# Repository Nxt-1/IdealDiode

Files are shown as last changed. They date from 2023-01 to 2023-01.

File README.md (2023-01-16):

# IdealDiode

A small implementation around a TI LM74700 ideal diode controller.

Ideal diode controllers are an idealistic approximation of a diode one-way current blocking functionality. This is achieved by switching an N-channel MOSFET when conduction is desired and using the MOSFET's internal body diode to block current otherwise. The TI part monitors the input and output voltage and drives the transistor when current need to block (i.e. when V_IN > V_OUT).

By fully saturating the transitor's gate, the voltage drop source and drain is in the order of tens of milivolts instead of the typical 700mV for a silicon diode.

## Use Case

This project is designed to be used when charching multiple 36V nominal (42V max) lithium battery packs in parallel. Specifically batteries with separated charge port BMS, that are always energised. If no protection was implemented, connecting the batteries in parallel could cause the full battery current of a battery with a higher state of charge to flow through the other battery's chargeport. Using a regular diode would effectively lower the maximum charge voltage by the diode's voltage drop, thus decreasing the usable battery capacity. Hence the ideal diode circuit.

## Specifactions

The device is designed to withstand 42V nomimal and a charge current of 5A.

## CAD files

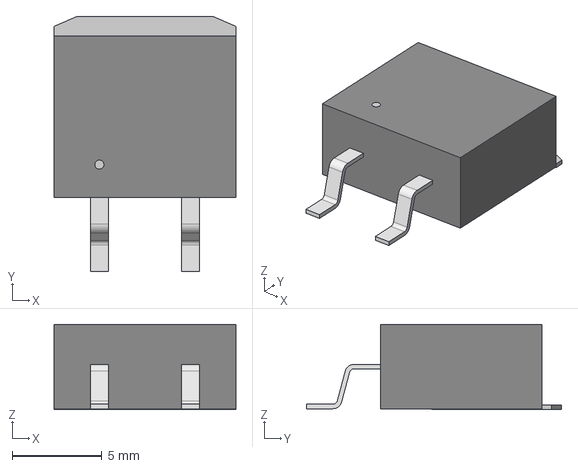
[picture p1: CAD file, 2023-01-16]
TRANS_R5009FNJ_ROM.step
10.1 x 14.2 x 4.75 mm

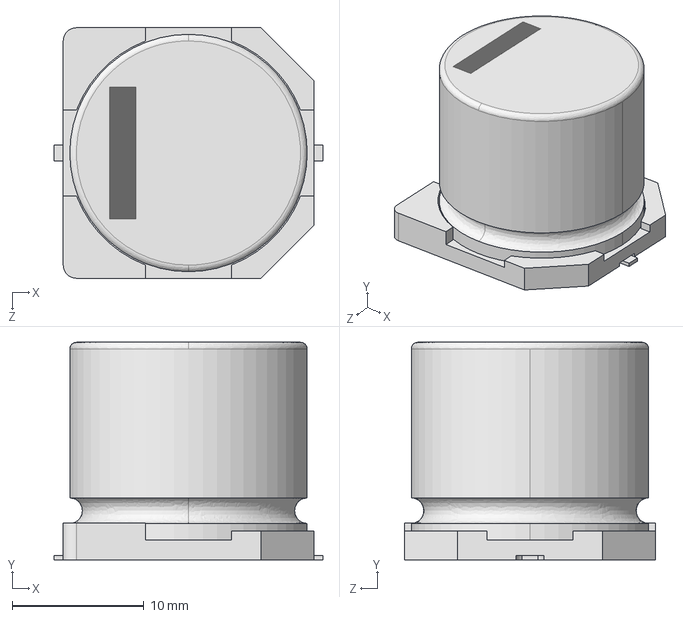
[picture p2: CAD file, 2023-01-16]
EEVFK2A221M.step
20.4 x 16.5 x 19.0 mm

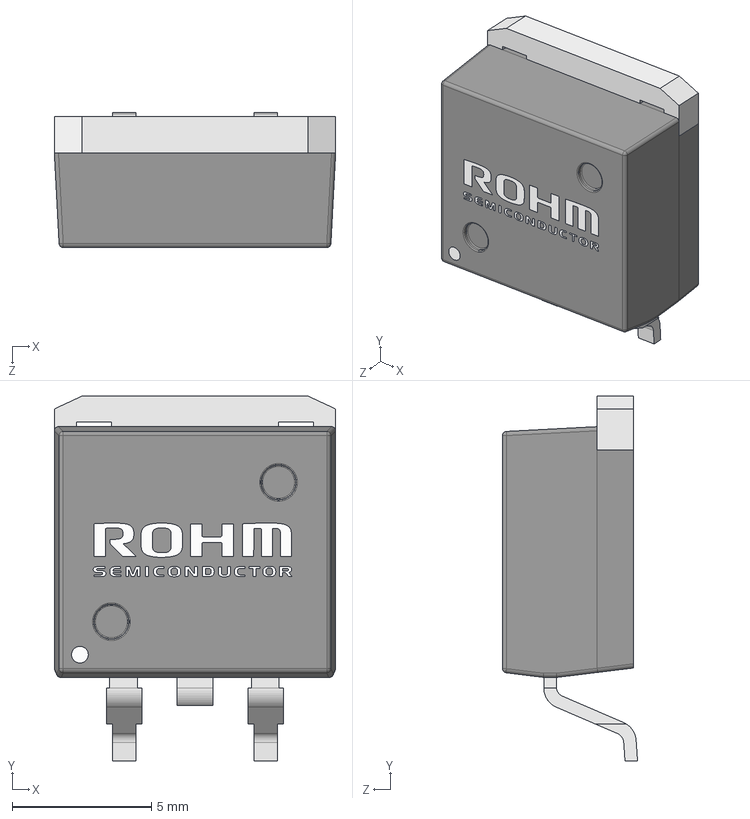
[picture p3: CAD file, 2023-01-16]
RSJ650N10TL.stp
10.1 x 13.1 x 4.85 mm
LPTS
Rohm Logo-LAPTOP-NQA1DCQ3

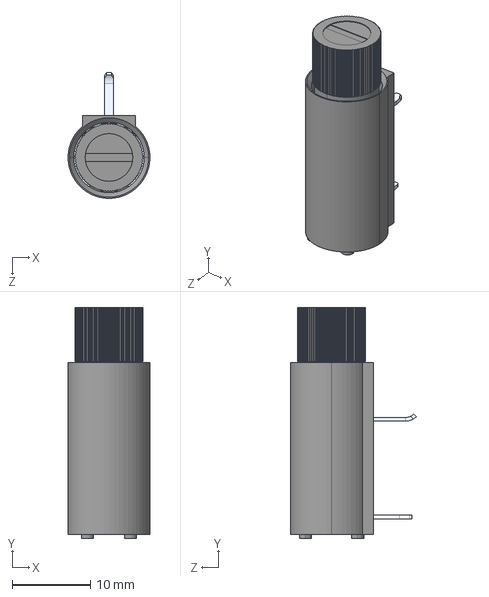
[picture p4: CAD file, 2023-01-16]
keystone-PN4525.STEP
10.5 x 29.6 x 16.1 mm

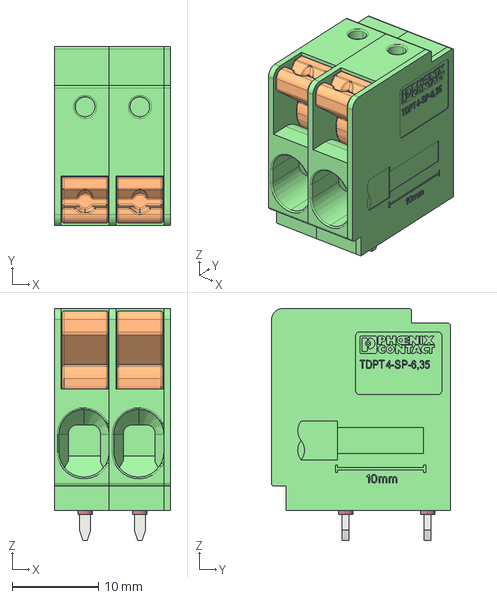
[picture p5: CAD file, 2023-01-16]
1017521.step
13.5 x 20.8 x 26.9 mm

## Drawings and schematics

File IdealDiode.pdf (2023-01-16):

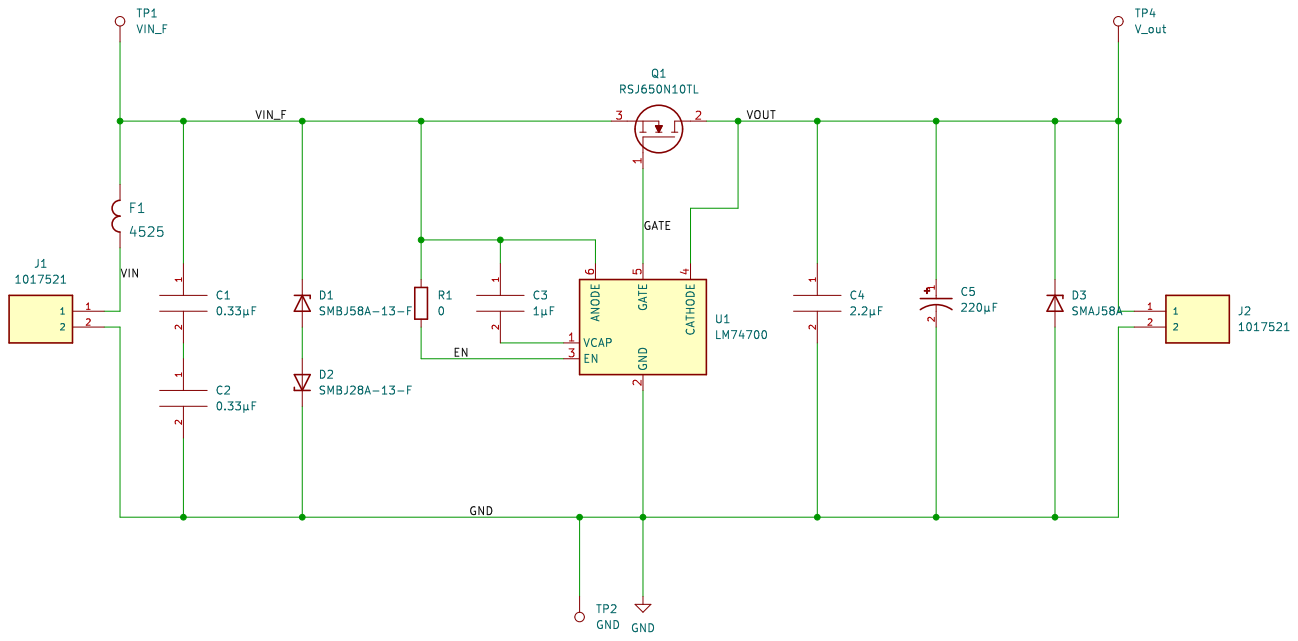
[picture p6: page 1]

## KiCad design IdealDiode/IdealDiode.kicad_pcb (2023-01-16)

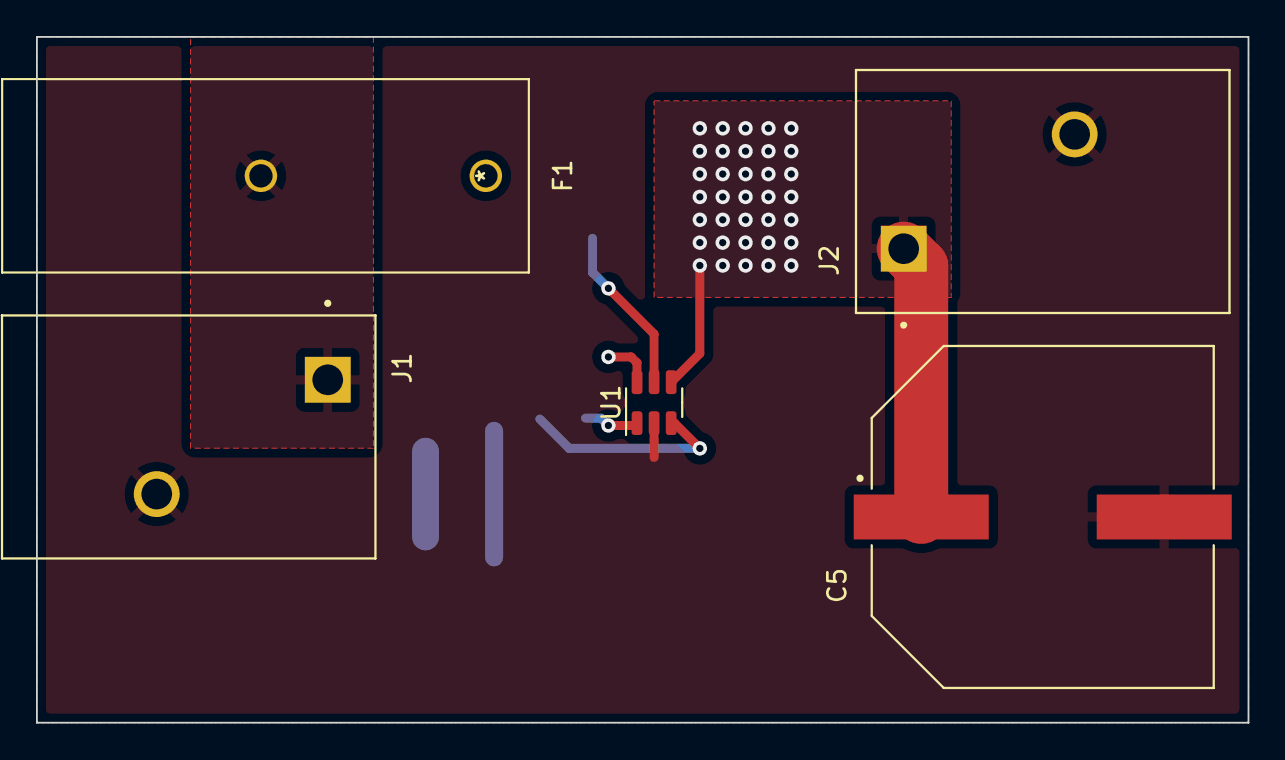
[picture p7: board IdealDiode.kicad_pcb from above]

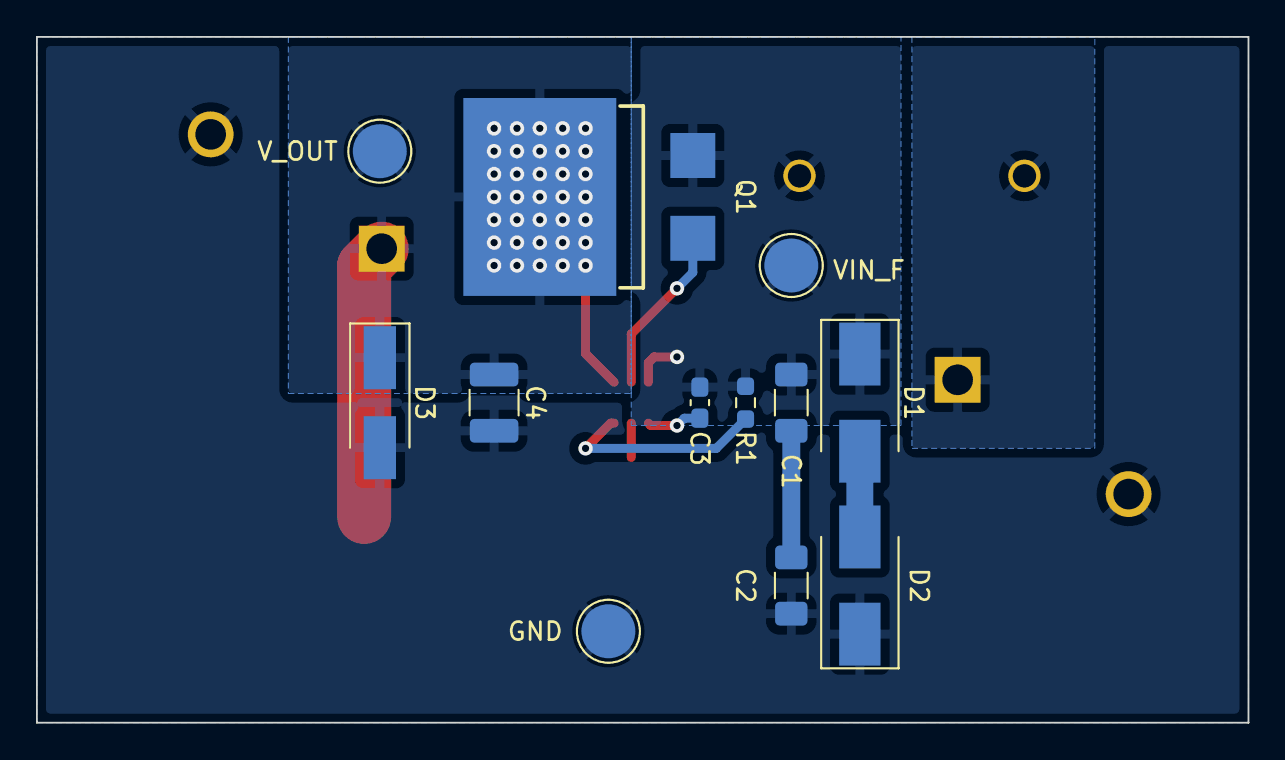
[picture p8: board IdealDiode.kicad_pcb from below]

Board: 2 copper layers, 67.3 x 38.1 mm, 17 parts (12 on the bottom side), 9 nets.

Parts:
C1, C2: 0.33µF; C_1206_3216Metric_Pad1.33x1.80mm_HandSolder
C3: 1µF; C_0603_1608Metric_Pad1.08x0.95mm_HandSolder
C4: 2.2µF; C_1210_3225Metric_Pad1.33x2.70mm_HandSolder
C5: 220µF; CAP_EEVFK2A221M
D1: SMBJ58A-13-F; D_SMB_Handsoldering
D2: SMBJ28A-13-F; D_SMB_Handsoldering
D3: SMAJ58A; D_SMA_Handsoldering
F1: FUSE_4525_KEY; 4525
GND: GND; TestPoint_Pad_D3.0mm
J1, J2: 1017521; PHOENIX_1017521
Q1: RSJ650N10TL; R6024KNJTL
R1: 0; R_0603_1608Metric_Pad0.98x0.95mm_HandSolder
U1: LM74700; SOT-23-6
VIN_F: VIN_F; TestPoint_Pad_D3.0mm
V_OUT: V_out; TestPoint_Pad_D3.0mm

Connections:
/EN: R1.2, U1.3 (EN)
/GATE: Q1.1, U1.5 (GATE)
/VIN: F1.2, J1.1
/VIN_F: C1.1, C3.1, D1.1 (K), F1.1, Q1.3, R1.1, U1.6 (ANODE), VIN_F.1
/VOUT: C4.1, C5.1, D3.1 (K), J2.1, Q1.2, U1.4 (CATHODE), V_OUT.1
GND: C2.2, C4.2, C5.2, D2.1 (K), D3.2 (A), GND.1, J1.2, J2.2, U1.2 (GND)
unnamed: C1.2, C2.1
unnamed: C3.2, U1.1 (VCAP)
unnamed: D1.2 (A), D2.2 (A)

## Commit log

2023-01-16 PCB files
    [1017521.step, EEVFK2A221M.step, IdealDiode.kicad_pcb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]
2023-01-16 Manufacturing output
    [IdealDiode-B_Cu.gbl, IdealDiode-B_Mask.gbs, IdealDiode-B_Paste.gbp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]
2023-01-16 Schematic pdf
